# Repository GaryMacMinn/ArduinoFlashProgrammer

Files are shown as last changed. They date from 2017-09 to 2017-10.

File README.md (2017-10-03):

# ArduinoFlashProgrammer
In designing my 65C02 retro computer I realised I'd be needing to program some Flash
memory chips to be the ROMs of my system. My old parallel EPROM programmer is long gone
so a new design was called for.

I had an Arduino Mega 2560 on the bench when the light dawned that this would be a good
platform to do this as it had plenty of I/O lines to operate the 27 address and data lines
and was fairly easy to program.

And so was born, the Arduino Flash Programmer.

The code shown here supports the AMD AM29F040B specifically as this is the Flash chip I'm
using. These are available on eBay and the like at cheap prices. They are a 4Mbit chip
arranged as 512k x 8bit. The sector operations work on 64k sectors so there are only 8 sectors
in this chip.

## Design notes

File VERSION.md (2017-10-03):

Current version of this project is **0.4** as at 3 October 2017.

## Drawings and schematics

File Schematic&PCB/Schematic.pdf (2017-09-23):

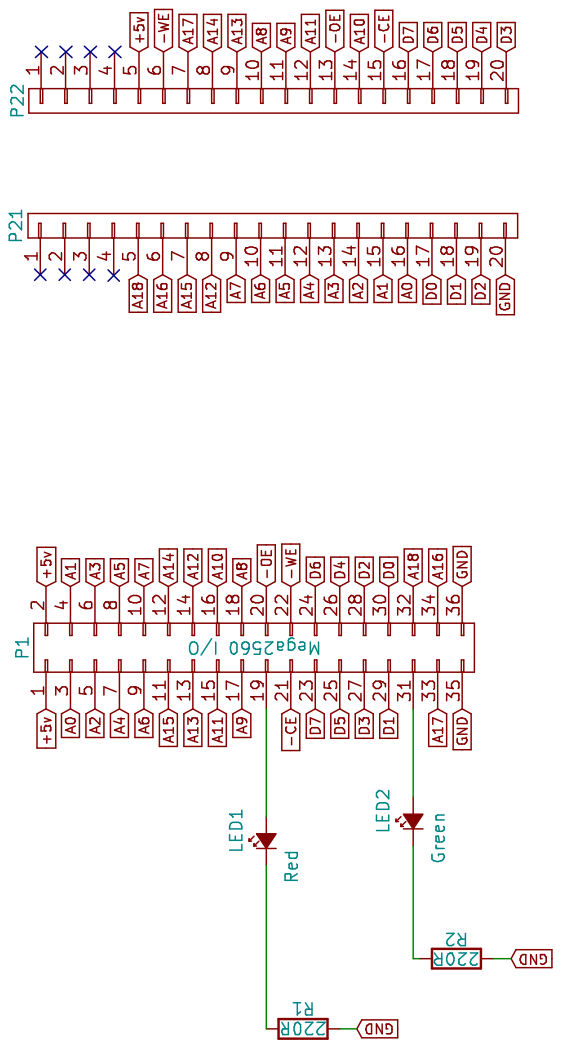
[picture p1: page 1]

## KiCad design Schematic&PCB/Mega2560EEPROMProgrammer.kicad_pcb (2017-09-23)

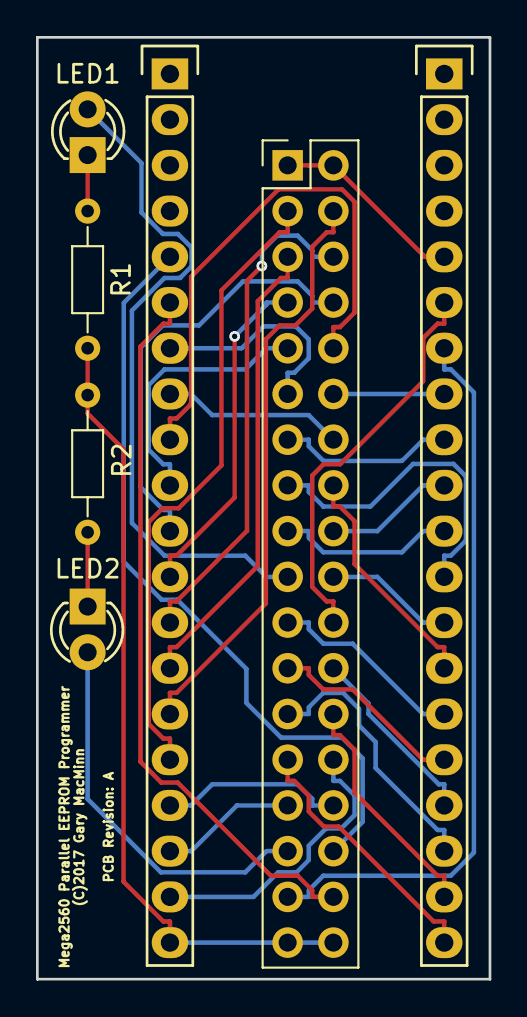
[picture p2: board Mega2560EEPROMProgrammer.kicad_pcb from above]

Board: 2 copper layers, 25.1 x 52.3 mm, 7 parts (0 on the bottom side), 36 nets.

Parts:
LED1: Red; LED-3MM
LED2: Green; LED-3MM
P1: Mega2560 I/O; Pin_Header_Straight_2x18_Pitch2.54mm
P21, P22: CONN_01X20; Socket_Strip_Straight_1x20
R1, R2: 220R; R_Axial_DIN0204_L3.6mm_D1.6mm_P7.62mm_Horizontal

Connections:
+5v: P1.1, P1.2, P22.5
-CE: P1.21, P22.15
-OE: P1.20, P22.13
-WE: P1.22, P22.6
A0: P1.3, P21.16
A1: P1.4, P21.15
A2: P1.5, P21.14
A3: P1.6, P21.13
A4: P1.7, P21.12
A5: P1.8, P21.11
A6: P1.9, P21.10
A7: P1.10, P21.9
A8: P1.18, P22.10
A9: P1.17, P22.11
A10: P1.16, P22.14
A11: P1.15, P22.12
A12: P1.14, P21.8
A13: P1.13, P22.9
A14: P1.12, P22.8
A15: P1.11, P21.7
A16: P1.34, P21.6
A17: P1.33, P22.7
A18: P1.32, P21.5
D0: P1.30, P21.17
D1: P1.29, P21.18
D2: P1.28, P21.19
D3: P1.27, P22.20
D4: P1.26, P22.19
D5: P1.25, P22.18
D6: P1.24, P22.17
D7: P1.23, P22.16
GND: P1.35, P1.36, P21.20, R1.2, R2.2
unnamed: LED1.1, R1.1
unnamed: LED1.2, P1.19
unnamed: LED2.1, R2.1
unnamed: LED2.2, P1.31

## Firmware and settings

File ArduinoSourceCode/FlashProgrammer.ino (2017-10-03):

/*
 * File Name:        FlashProgrammer.ino
 * Version:          V0.4
 * Created:          18 September 2017
 * Last Modified:    1 October 2017
 * Author:           Gary MacMinn
 * Purpose:          Flash Memory Programmer
 * 
 * Notes:
 *   PORTL is data bits 0-7
 *   PORTA is address bits 0-7
 *   PORTC is address bits 8-15
 */
  
// Define high address pins 
int AD16 = 53; 
int AD17 = 52; 
int AD18 = 51; 

// Define control pins
int ChipEN = 40;
int ReadEN = 39;
int WriteEN = 41;

// Define the LED pins
int LedRed = 38;
int LedGreen = 50;

const int MAX_SUBSTRINGS = 3;             // Maximum number of command parts
static char* substrings[MAX_SUBSTRINGS];  // Array of pointers to each command part after ParseString() has been called

char inputBuffer[45];
int cnt = 0;
boolean ready = false;

void setup()
{
  Serial.begin(115200);

  // set the LED pins as outputs and turn them off
  pinMode(LedRed,OUTPUT);
  digitalWrite(LedRed,LOW);
  pinMode(LedGreen,OUTPUT);
  digitalWrite(LedGreen,LOW);
  
  // set control signals to HIGH (All are active LOW)
  pinMode(ChipEN,OUTPUT);
  digitalWrite(ChipEN,HIGH);
  pinMode(ReadEN,OUTPUT);
  digitalWrite(ReadEN,HIGH);
  pinMode(WriteEN,OUTPUT);
  digitalWrite(WriteEN,HIGH);
  
  // configure the address lines as outputs and set them all to LOW
  DDRA = 255;
  PORTA = 0;
  DDRC = 255;
  PORTC = 0;
  pinMode(AD16,OUTPUT);
  digitalWrite(AD16,0);
  pinMode(AD17,OUTPUT);
  digitalWrite(AD17,0);
  pinMode(AD18,OUTPUT);
  digitalWrite(AD18,0);
  
  Serial.println();
  Serial.println("Flash Memory Programmer Ver 0.4");
  Serial.println("(C)2017 Gary MacMinn");

  // Flash the LEDs to show we're ready
  digitalWrite(LedRed,HIGH);
  delay(500);
  digitalWrite(LedRed,LOW);
  digitalWrite(LedGreen,HIGH);
  delay(500);
  digitalWrite(LedGreen,LOW);
  digitalWrite(LedRed,HIGH);
  delay(500);
  digitalWrite(LedRed,LOW);
  digitalWrite(LedGreen,HIGH);
  delay(500);
  digitalWrite(LedGreen,LOW);

  Serial.print("Ready> ");
}

void loop()
{
  if (readline(Serial.read(), inputBuffer, 80) > 0) {
    Serial.println("");
    
    ParseString(inputBuffer);

    ProcessCommand(substrings[0][0]);
    
    Serial.print("Ready> ");
  }
}

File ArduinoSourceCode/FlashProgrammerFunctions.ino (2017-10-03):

/*
 * File Name:        FlashProgrammerFunctions.ino
 * Version:          V0.4
 * Created:          18 September 2017
 * Last Modified:    1 October 2017
 * Author:           Gary MacMinn
 * Purpose:          Supporting functions for the Flash Programmer
 */

/****************************
 * Chip Operation Functions *
 ****************************/

/*******************************************************
 * FullChipErase                                       *
 *                                                     *
 *            +++ CAUTION - DESTRUCTIVE +++            *
 *                                                     * 
 * Erases the entire chip in one go. NO KIDDING!!!     * 
 *                                                     *
 *******************************************************/
void FullChipErase(void)
{
   Serial.println("Erasing the whole chip. Please wait...");
   
   DoWrite(0x5555L,0xAA);       // First output byte of Sector Erase 
   DoWrite(0x2AAAL,0x55);       // Second output byte of Sector Erase
   DoWrite(0x5555L,0x80);       // Third output byte of Sector Erase
   DoWrite(0x5555L,0xAA);       // Fourth output byte of Sector Erase
   DoWrite(0x2AAAL,0x55);       // Fifth output byte of Sector Erase
   DoWrite(0x5555L,0x10);       // Finalbyte and 0x10 Chip Erase Command
   
   delay(200);                  // Wait a bit for it to finish
   
   Serial.println("Erasure Complete.");
}

/***********************************************************
 * WriteFlash                                              *
 *                                                         *
 *            +++ CAUTION - DESTRUCTIVE +++                *
 *                                                         * 
 * Writes 16 bytes to Flash starting at the given address. * 
 * Command format is a "W", a colon ":", 5 HEX digits,     *
 * another colon":" and 16 bytes of 2 digit HEX.           *
 *                                                         * 
 * W:00000:0123456789ABCDEF0123456789ABCDEF                * 
 *                                                         * 
 * After writing, the 16 bytes are read and sent back      *
 * to the Serial port.                                     *
 *                                                         *
 ***********************************************************/
void WriteFlash(char* startL, char* data)
{
   unsigned long ctr;
   unsigned long WriteAddrL;
   char ReadNiblLo, ReadNiblHi;
   char readVal, writeVal, hexVal[3];
   
   WriteAddrL = Asc52Long(startL);

   for (ctr = 0 ; ctr <  16; ctr++)
   {
      hexVal[0] = data[ctr *2];
      hexVal[1] = data[ctr *2 + 1];
      hexVal[3] = 0;
      writeVal = Asc22Byte(hexVal);
      DoWrite(0x5555L,0xAA);                // First output byte of Byte Program 
      DoWrite(0x2AAAL,0x55);                // Second output byte of Byte Program
      DoWrite(0x5555L,0xA0);                // Third output byte of of Byte Program
      DoWrite(WriteAddrL+ctr,writeVal);     // Address and Data to store
      delay(1);
   }

   // Read back the section just written
   PrintHex5(WriteAddrL);
   Serial.print(":");   
   for (ctr = 0 ; ctr <  16; ctr++)
   {
      readVal = DoRead(WriteAddrL+ctr);
      ReadNiblLo = readVal & 0xF;
      ReadNiblHi = (readVal >>4) &0xF;
      Serial.print(ReadNiblHi,HEX);
      Serial.print(ReadNiblLo,HEX);
   } 
   Serial.println();
}

/*******************************************************
 * SectorErase                                         *
 *                                                     *
 *            +++ CAUTION - DESTRUCTIVE +++            *
 *                                                     * 
 * Erases the requested sector of the flash.           * 
 * Flash is divided in to 4K or 64k blocks or sectors. *
 * Check the flash memory datasheet for full details.  *
 *                                                     *
 *******************************************************/
void SectorErase(char* Sector)
{
   unsigned long Sector2Erase = Asc22Byte(Sector) << 8;
   Sector2Erase = Sector2Erase << 8;
   
//   unsigned long EraseAddrL;
   
//   Sector[0] = Sector[0] & 0x0F;
//   Sector[0] = Sector[0] <<4;
//   Sector[1] = Sector[1] - 0x30;
 
//   if (Sector[1] > 0x9)
//   {
///      Sector[1] = (Sector[1] & 0xF) + 9;
//   }
   
//   EraseAddrL = Sector[0] | Sector[1];
//   EraseAddrL = EraseAddrL << 12;
   
//   PrintHex5(EraseAddrL);
   Serial.print("Erasing sector "); Serial.println(Sector2Erase,HEX);
   
   DoWrite(0x5555L,0xAA);       // First output byte of Sector Erase 
   DoWrite(0x2AAAL,0x55);       // Second output byte of Sector Erase
   DoWrite(0x5555L,0x80);       // Third output byte of Sector Erase
   DoWrite(0x5555L,0xAA);       // Fourth output byte of Sector Erase
   DoWrite(0x2AAAL,0x55);       // Fifth output byte of Sector Erase
   DoWrite(Sector2Erase,0x30);    // Sector Address and 0x30 Sector Erase Command
}

/*********************************************************
 * ReadFlash                                             *
 *                                                       * 
 * Takes a start address as an unsigned long integer and * 
 * prints the 16 bytes of memory from that location.     *
 *                                                       *
 *********************************************************/
void ReadFlash(char* startL)
{
   unsigned long ctr;
   unsigned long ReadAddrL;
   char ReadNiblLo, ReadNiblHi;
   char readVal;
   
   ReadAddrL = Asc52Long(startL);
   
   PrintHex5(ReadAddrL); Serial.print(":");
   
   for (ctr = ReadAddrL; ctr < (ReadAddrL + 0x10); ctr++)
   {
       readVal = DoRead(ctr);
       ReadNiblLo = readVal & 0xF;
       ReadNiblHi = (readVal >>4) &0xF;
       Serial.print(ReadNiblHi,HEX);
       Serial.print(ReadNiblLo,HEX);
   } 
   Serial.println();
}
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

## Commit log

2017-09-23 Initial setup and uploads
    Addes source and circuit files.
    [Mega2560EEPROMProgrammer.kicad_pcb, Mega2560EEPROMProgrammer.sch]
2017-10-03 Fixed sector erase and implement full device erase.
    [FlashProgrammer.ino, FlashProgrammerFunctions.ino]
